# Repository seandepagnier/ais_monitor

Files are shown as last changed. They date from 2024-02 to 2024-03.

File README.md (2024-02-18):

This project is intended to create a simple device that monitors ship traffic and gps location
to sound audible alarms if there is potential for a collision.

It is inspired by the author's experience colliding with a cargo ship while under sail many
miles offshore in deep water.  Despite collision regulations regarding sail vs powered vessels,
commercial ships often do not keep an active watch, and do not set their radar to detect sailboats.

The primary AIS antenna had failed, and the author was very tired from many hours without sleep.
The intention is to create a reliable redundant backup alarm system with an internal 10 hour battery
to ensure an alarm will be heard even in the event of power failure.

The design uses a dAISy receiver coupled with a raspberry pi pico W.  The schematic provides isolated powersupply,
and maintains the battery at a standby level that does not greatly age the battery.   There is an external
speaker.  The nmea streams can be easily accesed via a tcp socket once the pi pico is connected to a wifi network.

free software targeting micropython performs all the calculations and functions and can be easily modified

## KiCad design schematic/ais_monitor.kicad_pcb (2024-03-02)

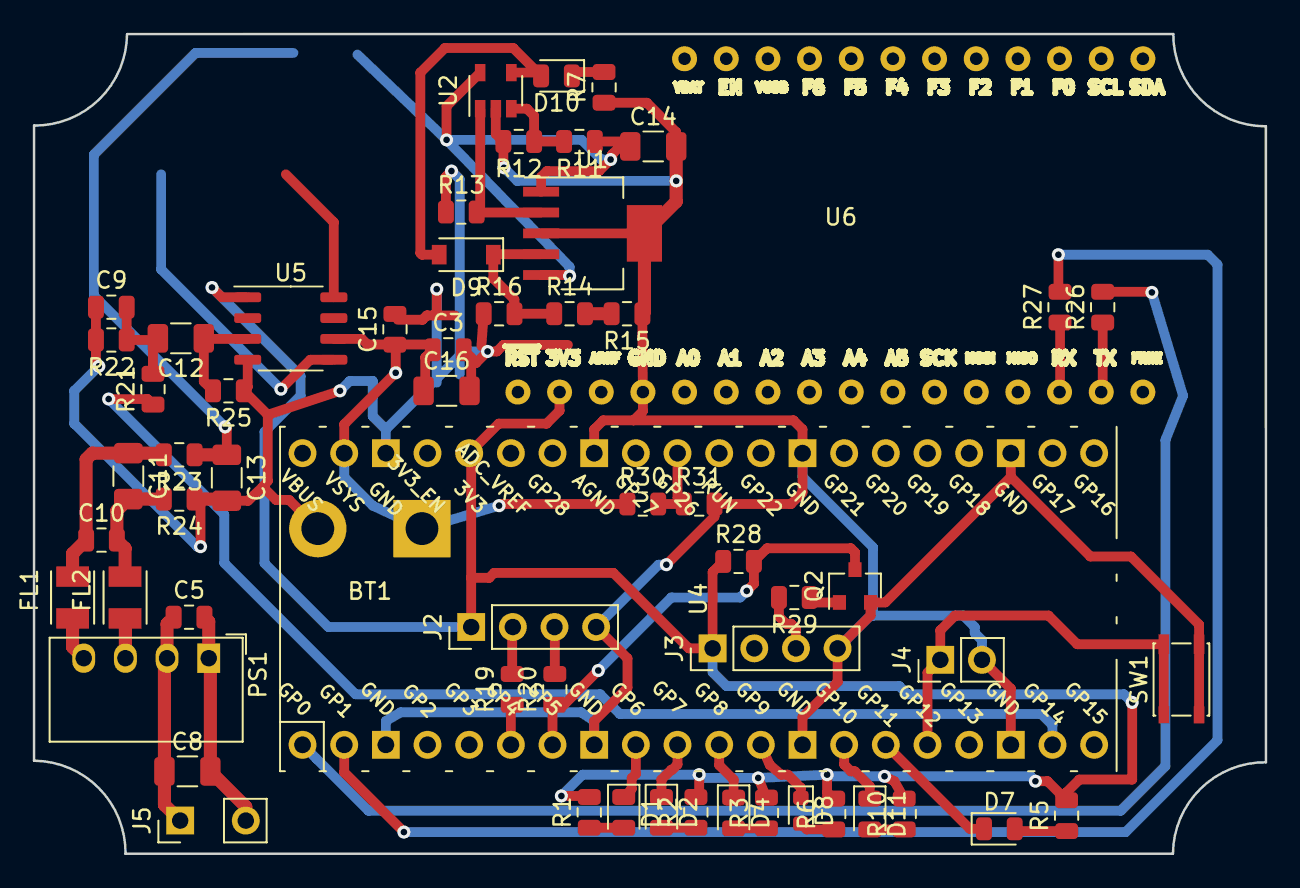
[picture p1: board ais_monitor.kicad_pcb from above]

Board: 2 copper layers, 75.1 x 50.0 mm, 60 parts (0 on the bottom side), 43 nets.

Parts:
BT1: Battery; SolderWirePad_1x02_P7.62mm_Drill2mm
C3: 1u; C_0805_2012Metric
C5, C9, C10, C15: 100n; C_0805_2012Metric
C8, C11, C12, C13, C14, C16: 10u; C_1206_3216Metric
D1: PWR; LED_0805_2012Metric
D2: AIS; LED_0805_2012Metric
D4: GPS; LED_0805_2012Metric
D7: MUTE; LED_0805_2012Metric
D8: SHIPS; LED_0603_1608Metric
D9: D; D_SOD-123
D10: CHARGE; LED_0805_2012Metric
D11: OWNSHIP; LED_0805_2012Metric
FL1, FL2: NFZ32BW151HN11L; FIL_NFZ32BW151HN11L
J2: GPS; PinHeader_1x04_P2.54mm_Vertical
J3: GPS RS232; PinHeader_1x04_P2.54mm_Vertical
J4: mute; PinHeader_1x02_P2.54mm_Vertical
J5: IN5; PinHeader_1x02_P2.54mm_Vertical
PS1: HLK-PM03; Converter_DCDC_muRata_CRE1xxxxxx3C_THT
Q2: Q_NMOS_DGS; SOT-23
R1, R5, R7, R19, R20, R26, R27, R28, R29: 2k4; R_0805_2012Metric
R2, R3, R6, R10: 1k2; R_0805_2012Metric
R11: 10k; R_0805_2012Metric
R12, R30, R31: 100k; R_0805_2012Metric
R13: 4.7; R_0805_2012Metric
R14: 20k; R_0805_2012Metric
R15, R25: 1k; R_0805_2012Metric
R16: 47k; R_0805_2012Metric
R21, R22: 100; R_0805_2012Metric
R23, R24: 1; R_0805_2012Metric
SW1: Mute; SW_SPST_PTS810
U1: TPS73701; SOT-223-6_TabPin3
U2: LM321; SOT-23-5
U4: Pico; RPi_Pico_SMD_TH
U5: PAM8302AAD; SOP-8_3.9x4.9mm_P1.27mm
U6: feather

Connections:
+3V3: J2.1, J3.1, R1.2, R2.2, R3.2, R5.2, R6.2, R10.2, R28.1, U4.36, U5.1, U6.14
+5V: C13.1, C14.1, R11.1, R23.1, U1.1, U1.5, U2.5
+BATT: BT1.1, C3.1, C15.1, C16.1, R13.1, R16.1, R30.1, U4.39, U5.6
AIS: D2.1, U4.10
GND: BT1.2, C3.2, C9.1, C13.2, C14.2, C15.2, C16.2, J2.4, J3.4, J4.2, Q2.2, R7.1, R12.2, R15.1, R22.2, R24.1, R25.1, R31.2, SW1.2, U1.3, U2.2, U4.3, U4.8, U4.13, U4.18, U4.23, U4.28, U4.33, U4.38, U5.4, U5.7, U6.16
GPS: D4.1, U4.11
MUTE: D7.1, U4.15
MUTEB: J4.1, SW1.1, U4.16
unnamed: C5.2, C8.2, J5.2, PS1.1
unnamed: C5.1, C8.1, J5.1, PS1.2
unnamed: C10.1, C11.1, FL1.2, R23.2
unnamed: C10.2, C11.2, FL2.2, R24.2
unnamed: C12.1, R25.2, U5.3
unnamed: C9.2, C12.2, R21.2, R22.1
unnamed: D1.2, R1.1
unnamed: D2.2, R2.1
unnamed: D4.2, R3.1
unnamed: D7.2, R5.1
unnamed: D8.2, R6.1
unnamed: D9.1, R14.1, R16.2, U1.4
unnamed: D10.1, R7.2
unnamed: D9.2, D10.2, U2.4
unnamed: D11.2, R10.1
unnamed: FL1.1, PS1.4
unnamed: FL2.1, PS1.3
unnamed: J2.2, R19.2
unnamed: J2.3, R20.2
unnamed: J3.3, R29.2
unnamed: Q2.1, R29.1
unnamed: R11.2, R12.1, U2.3
unnamed: R13.2, U1.2, U2.1
unnamed: R14.2, R15.2
unnamed: R21.1, U4.19
unnamed: R26.1, U6.27
unnamed: R27.1, U6.26
unnamed: R30.2, R31.1, U4.31
OWNSHIP: D11.1, U4.14
PWR: D1.1, U4.9
RX0: R27.2, U4.2
RX1: Q2.3, R20.1, R28.2, U4.7
SHIPS: D8.1, U4.12
TX0: R26.2, U4.1
TX1: R19.1, U4.6

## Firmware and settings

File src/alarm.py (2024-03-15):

#   Copyright (C) 2024 Sean D'Epagnier
#
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
import math, time
from sound import play_mp3
from config import config


# 1 = target within 1 mile
# 2 = potential target approaching
# 3 = gps failure
alarmtime = time.ticks_ms()
def alarm(index):
    # sound alarm at most every 10 seconds
    t = time.ticks_ms()
    global alarmtime
    if t - alarmtime < 10*1000:
        return
    alarmtime = t
    
    print("ALARM", index)
    if config['muted']:
        return
    
    if index == 1:
        play_mp3('slow.mp3')
    else:
        play_mp3('happy.mp3')

#helper trigonomotry functions
def sind(angle):
    return math.sin(math.radians(angle))

def cosd(angle):
    return math.cos(math.radians(angle))

def hypot(x, y):
    return math.sqrt(x*x + y*y)

def resolv(angle):
    while angle > 180:
        angle -= 360
    while angle < -180:
        angle += 360
    return angle

# convert latitude and longitudes into relative 2d coordinates
# this is slightly inaccurate assuming spherical earth model
# but using spherical coordinates (or elliptical earth coordinates)
# is much more complicated and slower, and this is sufficient for useful alarms
def simple_xy(lat1, lon1, lat2, lon2):
    x = cosd(lat1)*resolv(lon1-lon2) * 60
    y = (lat1-lat2)*60 # 60 nautical miles per degree
    return x, y

# from gps data for boat, and ais position data, determine if a collision is imminent
# if so, sound an alarm
def compute(gps_data, ais_data):
    if not gps_data or not 'sog' in ais_data:
        return

    # now compute cpa and tcpa
    sog = gps_data['sog']
    cog = gps_data['cog']
    asog = ais_data['sog']
    acog = ais_data['cog']
    if 'rot' in ais_data:
        acog += ais_data['rot']/60*5

    # x and y in relative distance in nautical miles to target
    x, y = simple_xy(gps_data['lat'], gps_data['lon'],
                     ais_data['lat'], ais_data['lon'])

    dist = hypot(x, y)
    ais_data['dist'] = dist
    if dist < config['proximity_dist']: # target is < 1 mile away, make alarm
        alarm(1)

    # velocity vectors in x, y
    bvx, bvy = sog*sind(cog), sog*cosd(cog)
    avx, avy = asog*sind(acog), asog*cosd(acog)

    # relative velocity of ais target
    vx, vy = avx - bvx, avy - bvy

    # the formula for time of closest approach is when the
    # derivative of the distance with respect to time is zero
    # d = (t*vx+x)^2 + (t*vy+y)^2
    # d = t^2*vx^2 + 2*t*vx*x + x^2 + t^2*vy^2 + 2*t*vy*y + y^2
    # dd/dt = 2*t*vx^2 + 2*vx*x + 2*t*vy^2 + 2*vy*y
    v2 = (vx*vx + vy*vy)
    if v2 < 1e-4: # tracks are nearly parallel courses
        t = 0
    else:
        t = (vx*x + vy*y)/v2

    # closest point of apprach distance in nautical miles
    d = hypot(t*vx - x, t*vy - y)
    
    # time till closest point of approach is in hours, convert to seconds
    t *= 3600

    if t < -30:  # tcpa is more than 30 seconds in past, no alarm
        return

    if t > 60*config['tcpa_time']: # tcpa is more than 10 minutes in future, no alarm
        return

    if d > config['tcpa_dist']: # cpa is more than 3 miles away, no alarm
        return
    
    # conditions allow for alarm
    alarm(2)

def anchor(gps_data):
    if not config['anchor']:
        return
    try:
        x, y = simple_xy(anchor_pos['lat'], anchor_pos['lon'],
                         gps_data['lat'], gps_data['lon'])
        dist = hypot(x, y) * 1852 # convert to meters
        if dist > config['anchor_radius']:
            alarm(3)
    

def ticks_ms():
    try:
        return time.ticks_ms()
    except:
        return int(time.time()*1000)

# for testing
if __name__ == '__main__':
    gps_data = {'latitude': 45, 'longitude': -70, 'sog': 5, 'cog': 90}
    ais_data = {'latitude': 45, 'longitude': -70.1, 'sog': 5.1, 'cog': 90, 'rot': 0}
    
    compute_alarm(gps_data, ais_data)

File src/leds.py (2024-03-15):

#   Copyright (C) 2024 Sean D'Epagnier
#
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
import time
from machine import Pin

# table for the various leds
led_indicies = {'pwr': 6,
                'ais': 7,
                'gps': 8,
                'ships': 9,
                'ownship': 10,
                'mute': 11,
                'anchor': 19,
                'ap': 21}

led_pins = {}
for pin, i in led_indicies.items():
    led_pins[pin] = Pin(i, Pin.OUT)
    led_pins[pin].low()

def value(name, v):
    led_pins[name].value(v)

led_pins['led'] = Pin("LED", Pin.OUT)
led_pins['led'].on()

led_timeouts = {}
def on_timeout(name, t=200):
    led_timeouts[name] = time.ticks_ms()+t
    value(name, True)

def timeout(t):
    for name, t0 in led_timeouts.items():
        if t > t0:
            value(name, False)

if __name__ == '__main__':
    for led in led_pins:
        value(led, 1)
        time.sleep(1)
        value(led, 1)
        time.sleep(.5)
    time.sleep(1)

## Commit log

2024-02-24 more updates
    [ais_monitor.sch]
2024-03-15 many updates
    [ais_monitor.sch]
